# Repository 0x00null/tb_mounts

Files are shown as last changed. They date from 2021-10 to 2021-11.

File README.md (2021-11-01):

# Machine mounts for Twisted Beast toys
This repository contains files for you to 3D print adapters to use your Twisted Beast toys with your fucking machine.

This stuff is **in no way endorsed or connected with Twisted Beast** - everything here is provided under the MIT licence, which means you use it all at your own risk.

------
**Build status:** 

------

**Latest Release:** [Download models.zip from here](https://github.com/0x00null/tb_mounts/releases/latest)

------

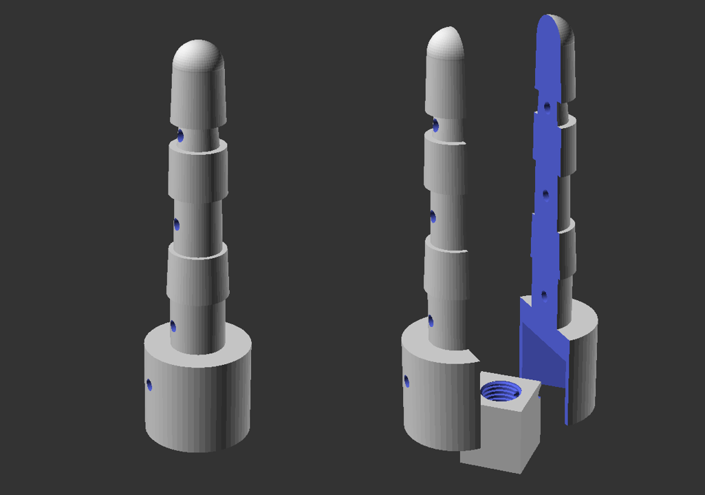
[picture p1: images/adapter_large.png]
3D render of the large adapter
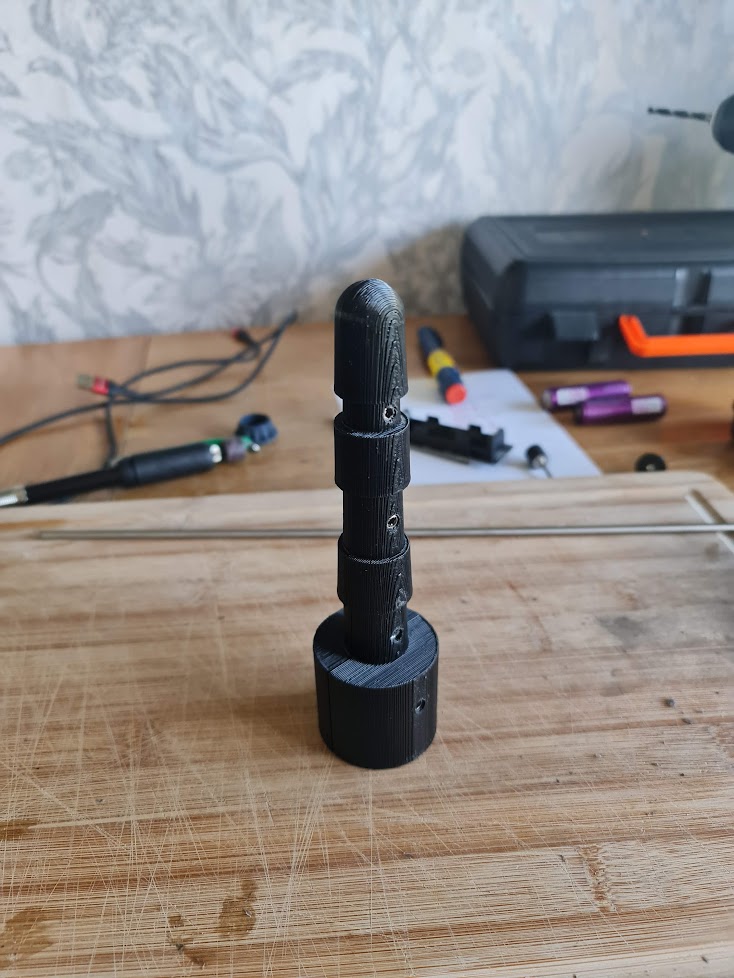
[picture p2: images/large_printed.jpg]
Printed and assembled adapter
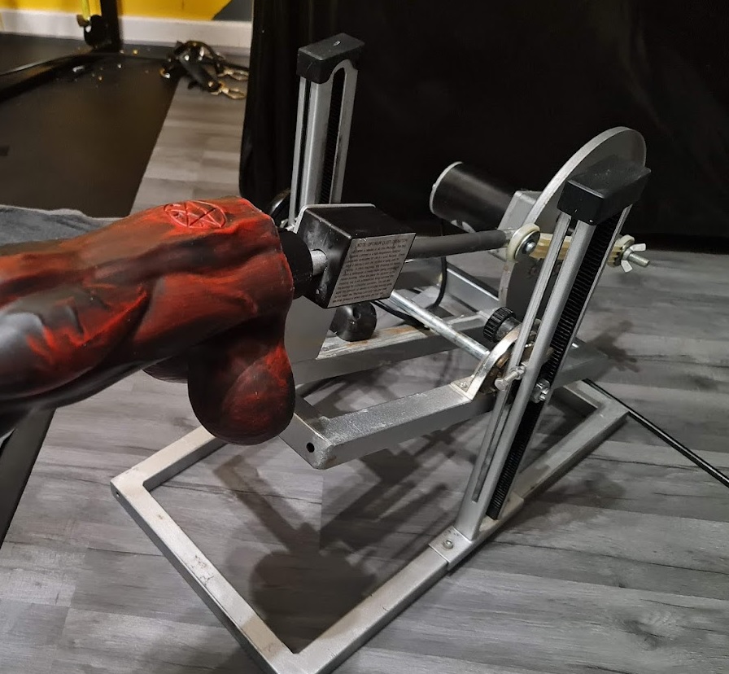
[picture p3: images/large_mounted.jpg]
Adapter mounted on a Maestro
||||
|---|---|---

## Toy Types
'Stems' are available for the following types of toy connection:
| Type | Filename |
| ---  |--- |
| Twisted Beast Large | `tb_large.stl` |
| Vac-U-Lock | `vac-u-lock.stl` |

## Machines
'Connection Blocks' are available for the following types of attachment:
| Type | Filename |
| ---  |--- |
| LoveBotz Maestro | `maestro.stl` |
| Knuckle Duster | `knuckles.stl` |

If you have any information on the threads used on other machines, let me know and I'll add a connector block!

## How to use
To print off your mount, you'll need:
 - A 3D printer
 - Filament (PLA is fine!)
 - Material for the pins to hold the whole thing together (I use 5mm steel tube, cut to length)

### Before you begin
The adapter is printed off in three parts - two halves of the 'stem' (the shaft which you insert into the toy) and a 'connector block' which slots into the bottom of the stem and is what attaches to your specific machine. The whole thing is held together with a set of pins which you push through holes in the stem.

It is really important that you print off the various bits in the correct orientation - 3D prints are typically weakest in the Z (up and down) direction, so you'll be printing the two halves of the stem flat against the bed - this ensures that your mount won't shear or snap where the stem meets the base.

The connector block is printed 'upright' as the threaded part needs to be as perfect as possible - it's a tradeoff between getting a good thread and strength.

**This way, if anything snaps, it'll be the connector block rather than the stem in your toy!**

You should use a strong material to make the locking pins - I use 5mm steel tube which I cut to length and round off the end edges to make inserting them easy. A blob of hot glue in each hole prevents the pins from coming out.

### Suggested Printer Settings
| Setting | Stem | Connector Block |
| --- | --- | --- |
| Layer Height | <= .3mm | <= .3mm |
| Top solid layers | 3 | all |
| Bottom solid layers | 3 | all |
| Shell perimiter layers | 2 | 2 |
| First Layer Height | 150% | 150% |
| First Layer Width | 150% | 150% |
| Infill %  | >= 30% | 100% |
| Infill Pattern | Rectilinear | Rectilinear |
| Infill Angles | 0, 45, 90, 135 | 0, 90 |
| Support | None | None |

### Let's go!
1. Grab the correct size .stl from the 'stems' folder
1. Print the two halves of the stem using a rotating rectilinear infill at 30%
1. Grab the correct connector block .stl from the 'connectors' folder
1. Print the connector block at 100% infill (don't change the orientation!)
1. Cut your pins to the correct size (see the table below)
1. Place your connector block into the base of the stem and push the longest pin through the hole
1. Place the rest of the pins in to their holes
1. Attach the whole thing to your machine, then slot your toy on
1. Bugger yourself senseless

**Side holes too small for your pins?** You can drill the holes out a little - but not too much! The pin should fit snugly and not move around on it's own. Add a blob of glue to each end to make sure everything is held securely.

## Modifying the mount
The mount is defined in an OpenSCAD file as a series of modules used to create the various parts of the mount. These all get combined together then the holes for the locking pins are 'drilled' through the final volume.

Which Stem or Connection Block is created depends on the value of one or two variables.

### Setting up your enviromment
You'll need to set up a few things to produce a custom `.stl` file:
1. Install OpenSCAD from [openscad.org](https://openscad.org)
1. (optional unless you're running a build) Ensure openscad is on your path
1. Install the Belfry OpenScad Library (used for threads) from [their github repo](https://github.com/revarbat/BOSL#installation)
1. Open mount.scad from the 'openscad' folder in this repo

### Building
If you want to perform a local build of all stems and connection blocks, run `node build.js`. You'll get a collection of Stem and Connection Block `.stl` files in the `output` folder, oriented for printing.

If you only want to generate a single model or two, open `mount.scad` from the `openscad` folder and start hacking.

### Output Settings
Key settings are at the top of the file:

#### `render_for_print`
When `true`, selected components are laid out for printing. When `false`, components are assembled as a preview of the completed mount.

#### `explosion_distance`
The amount to 'explode' the model when rendering in preview mode

#### `stem_type`
When `none`, no stem is rendered.
When `tb_large`, a Twisted Beast Large stem is rendered.
When `vac-u-lock`, a Vac-U-Lock compatible stem is rendered.

#### `connection_block_type`
When `none`, no connection block is rendered.
When `maestro`, a Maestro connection block is rendered.

### Basic Customisation
The settings you're most likely to need to change are the size and position of the pin holes to account for larger or smaller pins.

The `side_holes` vector contains the Z offsets of the holes, from bottom to top. **Be careful when changing the bottom-most hole** - it needs to pass through the top of the connector block, holding it in place and preventing it from sliding out of the bottom of the stem when in use.

The `side_hole_diameter` variable controls the size of the holes generated. It should .1mm to .2mm larger than the actual size of your pins.

### Advanced Customisation
There are comments throughout the file - have a read!

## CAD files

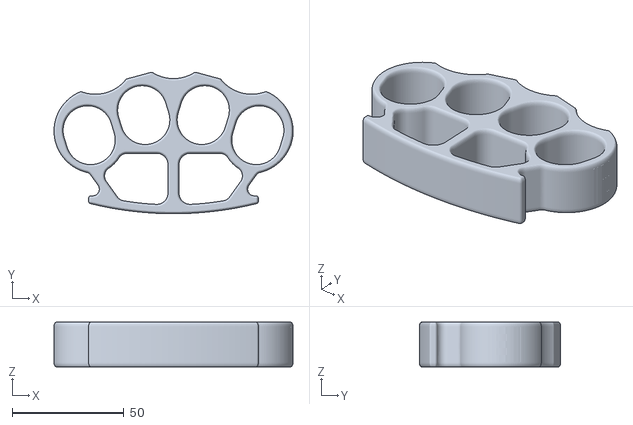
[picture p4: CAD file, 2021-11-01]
openscad/assets/knuckles/files/bower.stl
107.0 x 63.3 x 20.0

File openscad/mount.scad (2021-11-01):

include <BOSL/threading.scad>
$fn=60;

stem_type = "none";
connection_block_type = "none";

render_for_print = true;
explosion_distance = 20;

// Sections go from bottom to top
// each vector element is a vector of:
// 0: zOffset of the section
// 1: height of the section
// 2: d1 - diameter of the bottom of the section
// 3: d2 - diameter of the top of the section
// 4: domed - whether there is a domed top to the section
stem_types = [
    [
        "tb_large",
        [
            [0, 40, 45, 45, false], // base for connection block
            [40, 23, 23, 23, false],
            [63, 20, 26, 24, false],
            [83, 24, 20, 19, false],
            [107, 20, 24, 23, false],
            [127, 10, 17, 15, false],
            [137, 32, 22, 20, true],
        ]
    ],
    [
        "vac-u-lock",
        [
            [0, 40, 45, 45, false], // base for connection block
            [40, 25.62, 20.32, 20.32, false],
            [65.62, 20.32, 25.4, 21.59, false],
            [85.94, 36.2, 27.43, 21.59, true]
        ]
    ]
];


// z locations of side holes, from bottom to top
side_holes = [
    25,
    50,
    95,
    132
];

// Diameter of the side holes
side_hole_diameter = 5.2;

// Size of the connection block
connection_block_size = [27, 27, 30];

// additional space to leave above the connection block in the stem
connection_block_clearance_above = 1;

// additional space to leave around the connection block in the stem
connection_block_clearance_around = 0.5;

// We render slightly differently depending on the rendering mode
if (render_for_print == true) {
    
    // In print layout, we render the stem in two halves, face down on the bed
    if (stem_type != "none") {
        
        // we need to arrange the stem pieces nicely
        // Find the stem to render, then pass its sections to the render_sections module
        for(t = stem_types) {
            if (t[0] == stem_type) { // t[0] is the string name of the stem type
                
                // stem offsets are used to arrange the stems
                // t[1] is the vector of sections
                // t[1][0] is the mottom most section
                // t[1][0][0] is the z offset of the bottommost section
                
                // offset_x is based on the overall height of the stem
                // offset_y is based on the width of the first section (as it's the widest!)
        
                // zOffset of the topmost section, plus it's height
                stem_offset_x = (t[1][len(t[1]) - 1][0] + t[1][len(t[1]) - 1][1]) / 2;        
                
                // width of the bottommost section
                stem_offset_y = (t[1][0][2]) / 2;
                
                translate([-stem_offset_x, -stem_offset_y]) rotate([0, 90, 0]) half_stem();
                translate([stem_offset_x, stem_offset_y]) rotate([0, 90, 180]) half_stem();
            }
        }
        
        
    }
    
    if (connection_block_type != "none") {
        if (stem_type != "none") {
            // don't overlap with the stem halves!
            // Take the first diameter of the first section of the first type of stem as a rough guess
            connection_block_offset_y = (stem_types[0][1][0][2]) + connection_block_size[1];
            translate([0, connection_block_offset_y]) connection_block();
        } else {
            connection_block();
        }
    }
    
} else {
    
    if (stem_type != "none") {
        // Left half-stem
        translate([-explosion_distance, 0, 0]) half_stem();
        
        // Right half-stem
        translate([explosion_distance, 0, 0]) rotate([0, 0, 180]) half_stem();
    }
    if (connection_block_type != "none") { 
        translate([0, 0, -explosion_distance]) connection_block(); 
    }
}

//
// Renders half a stem for printing
//
module half_stem() {
    difference() {
        stem();
        translate([0, -100, 0]) cube([200, 200, 500]);
    }
}

//
// Renders the stem, with holes drilled through
//
module stem()
{
    difference() {        
        
        // Find the stem to render, then pass its sections to the render_sections module
        for(t = stem_types) {
            if (t[0] == stem_type) { // t[0] is the string name of the stem type
                stem_sections(t[1]); // t[1] is the section vector for this stem type
            }
        }
        
        // drill out side shafts
        side_shafts();
        
        // remove connection block void
        block_void_x_size = connection_block_size[0] + (2 * connection_block_clearance_around);
        block_void_y_size = connection_block_size[1] + (2 * connection_block_clearance_around);
        rotate([0, 0, 45]) { // we rotate the void so when printed, everything sits nicely
            translate([-(block_void_x_size / 2), -(block_void_y_size / 2)]) {
                cube([
                    block_void_x_size, // x
                    block_void_y_size, // y
                    connection_block_size[0] + (2 * connection_block_clearance_above) // z
                ]);
            }
        }
    }
}

module stem_sections(sections) {
    union() {
        for (section = sections) {      
            translate([0, 0, section[0]]) stem_section(section);
        }
    }
}

//
// Renders the specified stem section
//
module stem_section(section) {
    if (section[4] == true) {
        union() {
            cylinder(h=section[1]-(section[3] / 2), d1=section[2], d2=section[3]);
            translate([0, 0, section[1]-(section[3] / 2)]) sphere(d=section[3]);
        }
    } else {
        cylinder(h=section[1], d1=section[2], d2=section[3]);
    }
}

//
// Renders the shafts used to drill the side holes
//
module side_shafts() {
    for (hole_z = side_holes) {
        translate([0, 0, hole_z]) rotate([0, 90, 0]) cylinder(h=100, d=side_hole_diameter, center=true);
    }
}


//
// Renders the appropiate module based on the specified type
// Wouldn't it be nice if we could hold a pointer to a module in a vector... then we'd not have to do this nonsense!
//
module connection_block() {
            if (connection_block_type == "maestro") { connection_block_maestro(); }
            if (connection_block_type == "knuckles") { connection_block_knuckles(); }
}



//
// Renders a connection block for the Maestro fucking machine
//
module connection_block_maestro() {
    difference() {
        rotate([0, 0, 45]) union() { // rotate 45 for the side shaft to drill through properly
            difference() {
                // the block itself
                translate([-(connection_block_size[0] / 2), -(connection_block_size[1] / 2)]) cube(connection_block_size);
                
                // void we'll fill with the thread
                cylinder(h=30, d=20);
            }
            
            // Threaded nut to connect to the machine shaft
            metric_trapezoidal_threaded_nut(od=23, id=17, h=30, pitch=2, bevel=true, align=V_TOP);
        }
        
        side_shafts();
    
    }
}

//
// Renders a connection block for brass knuckles
//
module connection_block_knuckles() {   
    if (render_for_print == true) {
        translate([0, 45, connection_block_size[2] / 2]) rotate([0, 90, 0]) rotate([0, 0, 45]) connection_block_knuckles_core();
    } else {
        connection_block_knuckles_core();
    }
    
}

//
// Renders the core knuckles connector in 'preview' orientation
//
module connection_block_knuckles_core() {
    difference() {
        rotate([0, 0, 45]) union() { // rotate for the side shafts to drill properly
            translate([0, (connection_block_size[1] / 2), -(27.5 + 15)]) rotate([90, 0, 0]) union() {
                // Stack the knuckles to be the same depth as the connector block
                // the model is a little...wonky
                connection_block_knuckles_import();
                translate([0, 0, connection_block_size[2] - 22.9744]) connection_block_knuckles_import();
            }
            
            // the block itself
            translate([-(connection_block_size[0] / 2), -(connection_block_size[1] / 2), -15]) cube([connection_block_size[0], connection_block_size[1], connection_block_size[2] + 15]);
        }
        side_shafts();
    }
}

//
// Renders the resized knuckles model
//
module connection_block_knuckles_import() {
    render() intersection() {
        translate([0, 0, 12.01]) import("./assets/knuckles/files/bower.stl");
        translate([-150, -150, 0]) cube([300, 300, 20]);
    }
}

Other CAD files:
openscad_source/large.scad

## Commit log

2021-10-30 initial commit of large tb mount
    [large.scad, large_preview.stl, large_print_set.stl]
2021-10-30 doc updates, added exploded mode
    [large.stl, large_preview.stl, large_print_set.stl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]
2021-10-31 major refactor to make it nicer to extend later on
    [mount.scad]
2021-10-31 cleaned up old output files
    [large.stl, maestro.stl]
2021-11-01 build: include licence text in build config and log connector: added knuckles
    [bower.stl, mount.scad]
